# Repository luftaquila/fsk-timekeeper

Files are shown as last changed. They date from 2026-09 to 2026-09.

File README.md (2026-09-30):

# Formula Student Korea Timekeeper

Wireless LoRa timing instrument for Formula Student Korea dynamic events.

* One USB master, up to five battery-powered sensors (two in practice), one 921.3 MHz channel (KR920)
* Two modes: start → finish, laps (optional auto-stop)
* Console: one HTML file, Chrome / Edge (Web Serial)
  * https://luftaquila.github.io/fsk-timekeeper/
  * `fsk-timekeeper-console.html` from the [latest release](https://github.com/luftaquila/fsk-timekeeper/releases/latest)

## Usage notes

* The master is the board plugged into the console PC, and it must stay plugged in. Unplugged, it stops all radio activity; plugged back in, it starts a new session and any open run ends.
* Update the console and the firmware of every board together. The console refuses a master that reports another protocol version and says why.
* Flashing with several boards plugged in: `./flash.sh --serial <chip id>` (Windows: `.\flash.ps1 -Serial <chip id>`, not yet tested on Windows). The chip id is the 16-hex device id the console shows for the board; a board in the bootloader reports it too. A board still running a release from before chip-id serials reports 0001: give its port for that first update.

> [!NOTE]
> Assembly, usage and troubleshooting guides will follow.

## Development

<details>
<summary>click to expand</summary>

* Firmware
  * Requires: `arm-none-eabi-gcc` (with newlib-nano), `make`, `python3`
  * Build: `make -C device/firmware`
  * Test: `make -C device/firmware test`
* Console
  * Requires: Node.js 22
  * Build: `cd console && npm ci && npm run build:single`
  * Dev: `npm run dev` · Test: `npm test`
* Housings
  * Requires: OpenSCAD
  * Build: `make -C device/3d`
* Hardware
  * Requires: KiCad 10
  * Open: `device/hardware/fsk-timekeeper.kicad_pro`

</details>

## LICENSE

For non-commercial use only:

```
"THE BEERWARE LICENSE" (Revision 42):
LUFT-AQUILA wrote this project. As long as you retain this notice,
you can do whatever you want with this stuff. If we meet someday,
and you think this stuff is worth it, you can buy me a beer in return.
```

이 저장소의 모든 내용물은 비상업적 용도에 한해 얼마든지 자유롭게 사용할 수 있습니다.\
이 프로젝트가 마음에 든다면, 언젠가 우리가 만나게 되었을 때 맥주 한 잔 사 주세요.

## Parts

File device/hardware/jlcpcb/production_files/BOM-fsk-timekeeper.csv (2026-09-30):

Comment | Designator | Footprint | LCSC | Quantity
100nF | C1,C7 | C_0603_1608Metric | C14663 | 2
100pF | C5 | C_0603_1608Metric | C14858 | 1
10uF | C2,C3,C4,C8 | C_0603_1608Metric | C96446 | 4
110k | R2 | R_0603_1608Metric | C25805 | 1
1M | R1 | R_0603_1608Metric | C22935 | 1
330 | R3 | R_0603_1608Metric | C23138 | 1
4.7k | R4 | R_0603_1608Metric | C23162 | 1
47pF | C6 | C_0603_1608Metric | C1671 | 1
B5819W | D1 | D_SOD-123 | C8598 | 1
BAT54S | D2 | SOT-23 | C7420333 | 1
TPS61040DBV | U3 | SOT-23-5 | C7722 | 1

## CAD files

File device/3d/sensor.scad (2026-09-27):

// PCB Housing — FSK Timekeeper (wireless LoRa timing node) — SENSOR variant (sensor I/O only, no light)
// Board: 92 x 57 mm, corner r 3, 4x M2 mounting holes (86 x 51 rectangle),
// all tall components on the TOP side (18650 holder dominates the cavity height).
//
// Two parts:
//   lid  (본체 하우징)  — fully-rounded outer shell (ALL edges filleted) + ceiling + 4 self-tapping
//                         posts + connector cutouts + tripod boss. Open at the bottom.
//   base (바닥판)        — plate that inserts UP into the bottom opening of the lid (tucked under),
//                         carries the PCB on standoffs, fixed by the 4 screws into the lid posts.
//
// Assembly: M2 self-tapping screws inserted from OUTSIDE the base bottom pass through the
// base plate + PCB and self-tap into the posts hanging from the lid ceiling, pulling the
// base + PCB up against the posts and seating the base flush in the lid's bottom opening.
//
// Wall features (SENSOR variant — sensor I/O only; the light connector is not used):
//   - left  (-X): 1x Molex Mini-Fit Jr (J1 sensor +12V/SENSE). J2 (light GN/RD) opening is blanked off
//                 (solid wall). SMA antenna stays between the connector positions.
//   - right (+X): 1/4" tripod mount     (Ra-01 IPEX -> pigtail across the box -> antenna on the left)
//   - front (-Y): USB-C  (nRF52840 SuperMini) + 6mm toggle switch bushing (-Y wall, left)
//   - back  (+Y): blank
//
// Coordinate frame: PCB centred at XY origin; Z=0 at the outer bottom of the assembly.

/* [Rendering] */
part = "exploded";   // [base, lid, both, assembled, exploded]
show_pcb = true;     // PCB + 18650 reference in 'assembled' / 'exploded'
explode = 30;        // separation gap between stacked parts in 'exploded'

/* [PCB] */
pcb_l = 92;        // board length (X)
pcb_w = 57;        // board width  (Y)
pcb_r = 3;         // board corner radius
pcb_th = 1.6;      // board thickness
mount_inset = 3;   // mounting-hole inset from each edge (= corner radius)

/* [Shell] */
wall = 2.5;        // side wall thickness
lid_th = 2;        // lid ceiling thickness
base_th = 3;       // base plate thickness (>= edge_r so its bottom edge can be filleted)
pcb_clear = 0.5;   // gap between PCB edge and wall inner face
standoff_h = 2.5;  // PCB bottom height above base top (clears bottom-side 0603 caps ~0.5)
edge_r = 2.5;      // fillet radius for ALL outer edges of the body
batt_h = 21;       // *** ASSUMPTION: 18650 holder+cell height above PCB. MEASURE & adjust. ***
ra01_h = 6;        // *** ASSUMPTION: Ra-01 module height above PCB (limits how low the tripod box reaches). ***

/* [PCB-mount screws: base -> lid post, M2 self-tapping] */
post_d = 5.5;          // lid post outer diameter
post_style = "corner"; // [corner, rib, plain]
post_pad = 7;          // "corner" style: corner pad size
post_fillet = 2;       // "corner" style: rounding of the pad's cavity edge
post_rib = 2.4;        // "rib" style: rib thickness
post_pilot_d = 1.7;    // M2 self-tap pilot bore in post
post_pilot_depth = 16; // pilot depth up into post
so_d = 5.5;            // base standoff outer diameter
screw_clear_d = 2.6;   // M2 shaft clearance (through base + PCB)
head_d = 4.4;          // counterbore for screw head (base bottom)
head_h = 2;            // counterbore depth
base_fit = 0.3;        // base clearance per side inside the lid bottom opening

/* [Molex Mini-Fit Jr cutouts — left/-X wall] */
// KiCad +Y is screen-DOWN, OpenSCAD +Y is UP  ->  model_Y = 139.5 - boardY  (Y is flipped).
// Opening centre = connector WIDTH centre (pin centroid), NOT the footprint origin: the 2 circuits sit
// +2.1mm (local-X) from the origin -> J1 boardY 140.65 -> 139.5-(140.65-2.1) = 0.95; J2 -> -11.25.
molex_y = [0.95, -11.25];   // connector opening Y centres (model)
molex_cut_w = 11;          // opening width (Y) — clears the 9.6mm shroud (Molex SD-5569) + margin
molex_cut_h = 11;          // opening height above PCB (Z) — 9.6mm shroud + right-angle standoff (sensor variant: lowered 1mm, latch slot drops with it but keeps its height)
molex_latch_w = 4;         // latch slot width — clears the 3.0mm engaging tongue (Molex SD-5557 ".12[3.0]"); the 5.4mm is the external release handle, not through the wall (sensor variant: widened 0.5mm)
molex_latch_h = 4.5;       // latch slot extra height — must clear the latch at MAX deflection during mating (rest ~2.5mm + flex), not just at rest; SD shows rest only, so kept generous (sensor variant: net -0.5mm from baseline 5)

/* [USB-C cutout — -Y wall] */
// USB-C sits on the SuperMini's short end (board Y~167, at the -Y wall). Its X centre is the MODULE-WIDTH
// centre, NOT the footprint origin (origin = a corner pad): end pads span board X 140.47..155.71 ->
// centre 148.09 -> model 6.09. Port CENTRE height is measured 6.4mm above the PCB bottom face.
usb_x = 6.1;          // X centre of the USB-C port (model)
usb_cut_w = 13;       // opening width (X) incl. cable-boot clearance
usb_cut_h = 7;        // opening height (Z)
usb_above_bot = 6.4;  // port CENTRE height above the PCB bottom face (measured)

/* [Toggle switch bushing hole — -Y wall, LEFT (-X), clear of the Molex] */
// 6mm bushing toggle (MTS-/STM- 6mm series). The switch body needs a sw_cube clearance box
// reaching inward from the -Y wall; it is kept EAST (+X) of the Molex courtyard, which reaches
// model X -27.45 (J1 Y -4.35..+6.25, J2 Y -16.55..-5.95, Z 7.1..18), and ABOVE the PCB.
sw_d = 6;          // bushing through-hole (6mm toggle)
sw_cube = 14;      // required interior body-clearance cube (edge length)
sw_x = -15;        // hole X centre on the -Y wall (moved +5mm toward the tripod/+X side); cube -X edge -22 clears Molex (+X edge -27.45)
sw_z = 19;         // hole Z centre: cube spans z 12..26 -> above PCB + low parts (incl. L1 ~z10), below ceiling 37.6

/* [SMA antenna hole — -X (left) wall] */
// sensor variant (J2/light blanked off): bore centred above box mid-height (Z), and in Y midway between
// the -Y end of the J1 (sensor) opening and the -Y inner wall, nudged toward the connector, into the
// wall freed where J2 used to be.  (ant_y/ant_z are computed in the derived section, where inner_w exists.)
ant_d = 6.5;                             // SMA bulkhead through-hole

/* [Tripod mount — +X (right) wall, ceiling-integrated box (prints support-free)] */
// On the right wall (antenna side). A box hangs from the ceiling (fused to ceiling + wall; printed
// ceiling-down it is a solid column off the bed -> no support) and extends DOWN to the 1/4" bore,
// which sits at the vertical CENTRE of the face. At Y=0 the battery is absent (cell ends ~Y+8, the
// +X contact is at Y+14..+21), so only the low Ra-01 module limits how far down the box reaches.
tri_box_w = 12;    // box width (Y)
tri_y = -1.5;      // box Y centre — shifted -Y off the face centre so it clears the battery holder body (-Y edge ~ +6.75)
tri_box_d = 10;    // box depth into the cavity (X from the wall)
tri_pilot_d = 5.7; // 1/4"-20 self-tap pilot in plastic (was 5.4 — too tight to thread in)
tri_depth = 8;     // thread engagement depth from the outer wall face
tri_gap = 2;       // clearance between the box bottom and the Molex envelope

/* [Quality] */
$fn = 64;

// ---------- derived ----------
inner_l = pcb_l + 2*pcb_clear;
inner_w = pcb_w + 2*pcb_clear;
outer_l = inner_l + 2*wall;
outer_w = inner_w + 2*wall;
inner_r = pcb_r + pcb_clear;
outer_r = inner_r + wall;

base_l = inner_l - 2*base_fit;       // plugs the bottom opening
base_w = inner_w - 2*base_fit;
base_r = inner_r - base_fit;

pcb_bot_z = base_th + standoff_h;    // PCB underside
pcb_top_z = pcb_bot_z + pcb_th;      // PCB top surface
usb_z     = pcb_bot_z + usb_above_bot;   // USB-C port centre Z (measured from the PCB bottom face)
// height: max of battery, latch-slot reach, and "tripod bore at face centre while its box clears the Ra-01"
cavity    = max(batt_h + tri_gap, molex_cut_h + molex_latch_h + 2, 2*(pcb_top_z + ra01_h + 4 + tri_pilot_d/2) - pcb_top_z - lid_th);
ceil_z    = pcb_top_z + cavity;      // lid inner ceiling
outer_h   = ceil_z + lid_th;         // overall height
post_len  = ceil_z - pcb_top_z;      // = cavity

tri_hole_z  = outer_h/2;                          // 1/4" bore at the vertical CENTRE of the right face
tri_box_bot = pcb_top_z + ra01_h + 2;             // box hangs from the ceiling down to here (clears the Ra-01 module)
ant_y       = ((molex_y[0] - molex_cut_w/2) + (-inner_w/2)) / 2 + 1;   // midway: sensor-hole -Y end <-> -Y inner wall, +1mm toward the connector
ant_z       = outer_h/2 + 8;                      // sensor variant: above box mid-height

mx = pcb_l/2 - mount_inset;          // 43
my = pcb_w/2 - mount_inset;          // 25.5
mount_pos = [[-mx,-my],[mx,-my],[-mx,my],[mx,my]];

eps = 0.01;
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

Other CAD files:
device/3d/master.scad

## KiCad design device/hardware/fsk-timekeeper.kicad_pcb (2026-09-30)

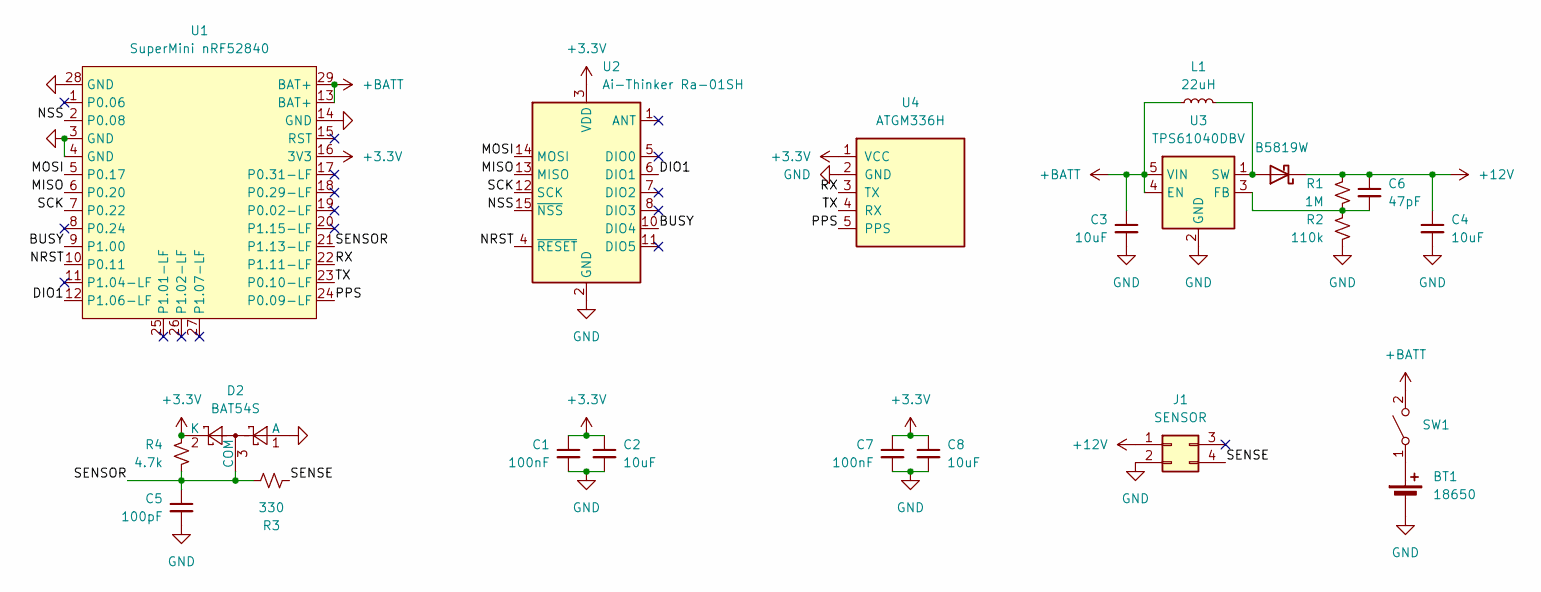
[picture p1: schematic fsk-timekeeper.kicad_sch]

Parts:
BT1: 18650; BatteryHolder_Keystone_1042_1x18650
C1, C7: 100nF; C_0603_1608Metric; LCSC C14663
C2, C3, C4, C8: 10uF; C_0603_1608Metric; LCSC C96446
C5: 100pF; C_0603_1608Metric; LCSC C14858
C6: 47pF; C_0603_1608Metric; LCSC C1671
D1: B5819W; D_SOD-123; LCSC C8598
D2: BAT54S; SOT-23; LCSC C7420333
J1: SENSOR; Molex_Mini-Fit_Jr_5569-04A2_2x02_P4.20mm_Horizontal
L1: 22uH; L_Sunlord_MWSA0603S
R1: 1M; R_0603_1608Metric; LCSC C22935
R2: 110k; R_0603_1608Metric; LCSC C25805
R3: 330; R_0603_1608Metric; LCSC C23138
R4: 4.7k; R_0603_1608Metric; LCSC C23162
SW1: SW_SPST; PinHeader_1x02_P2.54mm_Vertical
U1: SuperMini nRF52840; SuperMini_NRF52840
U2: Ai-Thinker Ra-01SH; Ai-Thinker-Ra-01-LoRa
U3: TPS61040DBV; SOT-23-5; LCSC C7722
U4: ATGM336H; ATGM336H_GPS_Module

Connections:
+3.3V: C1.1, C2.1, C7.1, C8.1, D2.2 (K), R4.2, U1.16 (3V3), U2.3 (VDD), U4.1 (VCC)
+12V: C4.1, C6.1, D1.1 (K), J1.1, R1.1
+BATT: C3.1, L1.1, SW1.2 (B), U1.13 (BAT+), U1.29 (BAT+), U3.4 (EN), U3.5 (VIN)
/BUSY: U1.9 (P1.00), U2.10 (DIO4)
/DIO1: U1.12 (P1.06-LF), U2.6 (DIO1)
/MISO: U1.6 (P0.20), U2.13 (MISO)
/MOSI: U1.5 (P0.17), U2.14 (MOSI)
/NRST: U1.10 (P0.11), U2.4 (~RESET)
/NSS: U1.2 (P0.08), U2.15 (~NSS)
/PPS: U1.24 (P0.09-LF), U4.5 (PPS)
/RX: U1.22 (P1.11-LF), U4.3 (TX)
/SCK: U1.7 (P0.22), U2.12 (SCK)
/SENSE: J1.4, R3.1
/SENSOR: C5.1, D2.3 (COM), R3.2, R4.1, U1.21 (P1.13-LF)
/TX: U1.23 (P0.10-LF), U4.4 (RX)
GND: BT1.2 (-), C1.2, C2.2, C3.2, C4.2, C5.2, C7.2, C8.2, D2.1 (A), J1.2, R2.2, U1.3 (GND), U1.4 (GND), U1.14 (GND), U1.28 (GND), U2.2 (GND), U2.9 (GND), U2.16 (GND), U3.2 (GND), U4.2 (GND)
unnamed: BT1.1 (+), SW1.1 (A)
unnamed: D1.2 (A), L1.2, U3.1 (SW)
unnamed: C6.2, R1.2, R2.1, U3.3 (FB)

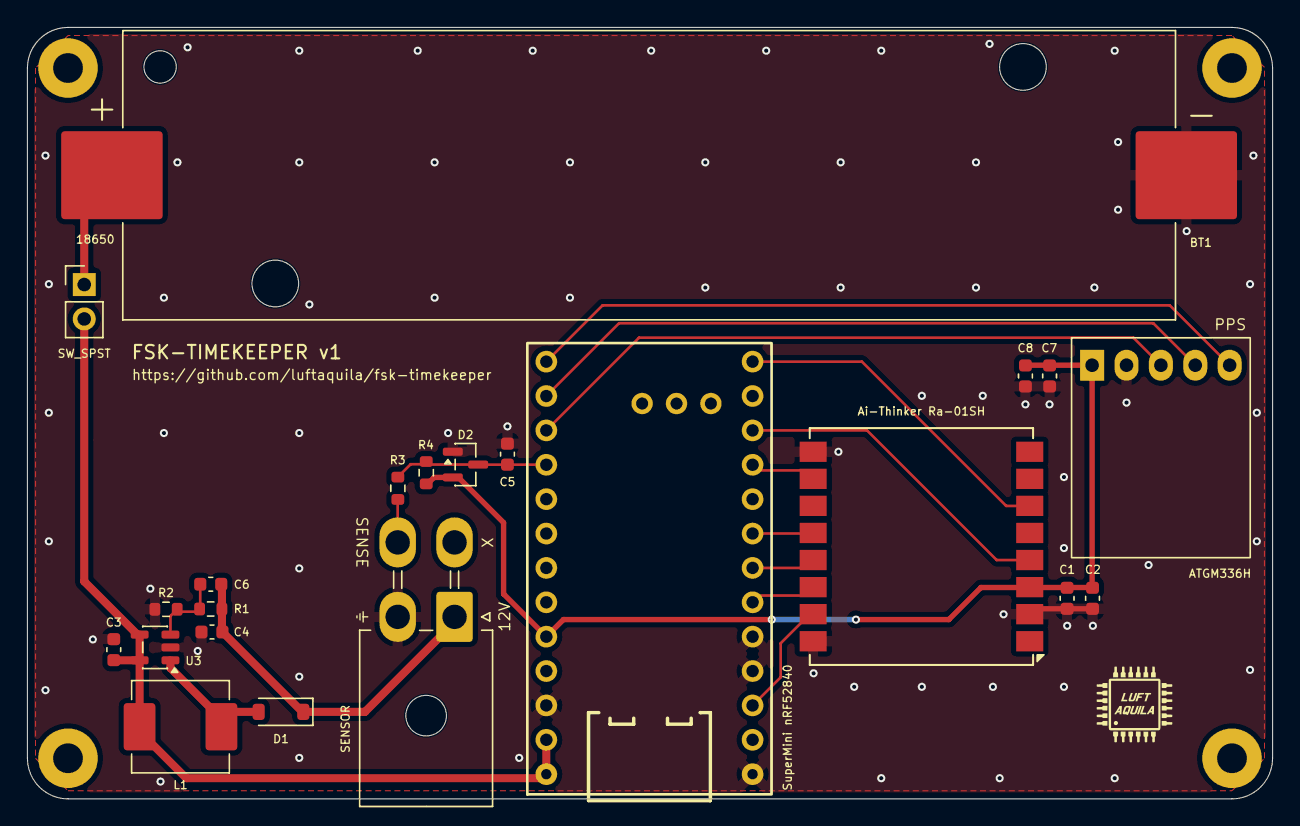
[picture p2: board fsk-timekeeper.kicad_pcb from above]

Board: 2 copper layers, 92.0 x 57.0 mm, 22 parts (0 on the bottom side), 19 nets.

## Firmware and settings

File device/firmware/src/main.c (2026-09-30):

/* One master and up to MAX_NODES sensors on one channel and one timebase; one
 * binary, role decided at boot from USB (DESIGN §8).
 *
 * MASTER = the board a PC enumerates over USB-CDC: beacons, collects sensor
 * records into the host queue and speaks the FSK-WL line protocol (proto_usb.h).
 * SENSOR = any other board: syncs to beacons, captures SENSOR edges in hardware
 * and uplinks them in its slot (mac_sensor.h).
 */
#include <stdint.h>
#include <stddef.h>

#include "board.h"
#include "capture.h"
#include "config.h"
#include "errlog.h"
#include "fault.h"
#include "gpio.h"
#include "gps.h"
#include "keystore.h"
#include "mac_master.h"
#include "mac_sensor.h"
#include "master_queue.h"
#include "meas.h"
#include "node_id.h"
#include "power.h"
#include "proto_usb.h"
#include "radio.h"
#include "secure.h"
#include "usb.h"
#include "nrf.h"

/* Pump USB up to ROLE_SETTLE_MS for a PC to enumerate us: master when one does.
 * Decided once; a host that later suspends the bus does not change it. */
static int role_decide_master(void)
{
    uint32_t t0 = board_millis();
    for (;;) {
        usb_task();
        if (usb_host_present()) { return 1; }
        if ((uint32_t)(board_millis() - t0) >= ROLE_SETTLE_MS) { return 0; }
    }
}

/* `K <64-hex>` on any board: write the fleet key and use it at once. There is no
 * read-back command. */
static void provision_key(void)
{
    if (keystore_write(pu_setkey()) == 0) {
        sec_reload();
        pu_emit_ack("K");
    } else {
        pu_emit_err("keyfail");
    }
}

static void service(uint32_t now)
{
    usb_task();
    pu_service(now);
    fault_service(now);
    board_hfxo_service();
}

/* ===== bring-up ========================================================== */

/* Radio, TIMER1 and the role's captures; 0 when up. Fail closed: no radio or
 * TIMER1 work on HFINT. Until it is up the board keeps USB provisioning and
 * retries with backoff. */
static int bring_up(int master)
{
    if (!board_hfclk_xtal()) { return -1; }
    int st = radio_begin();
    if (st != 0) { return st; }
    capture_init();
    if (master) {
        capture_pps_enable();
        gps_init();
    } else {
        capture_sensor_enable();
    }
    return 0;
}

typedef struct {
    uint32_t at_ms;
    uint32_t backoff_ms;
} retry_t;

static void retry_init(retry_t *r)
{
    r->backoff_ms = RADIO_BOOT_RETRY_MS;
    r->at_ms = board_millis() + r->backoff_ms;
}

/* 1 once a due retry has brought the board up. */
static int retry_bring_up(retry_t *r, int master, uint32_t now)
{
    if ((int32_t)(now - r->at_ms) < 0) { return 0; }
    el_note(EL_RADIO_RESET);
    if (bring_up(master) == 0) { return 1; }
    r->backoff_ms = r->backoff_ms * 2u > RADIO_RESET_BACKOFF_MAX_MS ? RADIO_RESET_BACKOFF_MAX_MS : r->backoff_ms * 2u;
    r->at_ms = board_millis() + r->backoff_ms;
    return 0;
}

/* ===== sensor ============================================================ */

static mac_sensor_t g_sensor;

static void run_sensor(int st)
{
    if (st == 0) { mac_sensor_init(&g_sensor, node_sender_id(), fault_reset_reason()); }
    retry_t retry;
    retry_init(&retry);
    uint32_t last_blink = board_millis();
    for (;;) {
        uint32_t now = board_millis();
        service(now);
        int c;
        while ((c = usb_read_byte()) >= 0) {
            switch (pu_feed(c)) {
            case PU_CMD_SETKEY: provision_key(); break;
            case PU_CMD_ID:
                pu_emit_identity(node_devid_hi(), node_devid_lo(), 0, fault_reset_reason());
                pu_emit_ack("ID");
                break;
            case PU_CMD_PING: pu_emit_ack("PING"); break;
            case PU_CMD_BAD: pu_emit_err("badcmd"); break;
            default: break;
            }
        }
        if (st != 0) { /* no radio / no crystal: provisioning, and a retry now and then */
            if (retry_bring_up(&retry, 0, now)) {
                st = 0;
                mac_sensor_init(&g_sensor, node_sender_id(), fault_reset_reason());
                continue;
            }
            if ((uint32_t)(now - last_blink) >= 1000u) { last_blink = now; board_led_toggle(); }
            continue;
        }
        mac_sensor_step(&g_sensor);
    }
}

/* ===== master ============================================================ */

static mq_t g_queue;
static mac_master_t g_mac;
static uint32_t g_hfxo_stops; /* board_hfxo_stops() already handled */

/* A master HFXO fault ends the timebase session: its marker is queued ahead of
 * any record of the new session, which starts once the crystal is back. A stop
 * whose restart already finished counts too. */
static int master_clock_check(void)
{
    static int faulted, reported;
    static uint64_t at;
    static uint32_t boot;
    uint32_t stops = board_hfxo_stops();
    int stopped = stops != g_hfxo_stops;
    g_hfxo_stops = stops;
    if ((!board_hfclk_xtal() || stopped) && !faulted) {
        at = capture_now64();
        boot = sec_boot_id();
        faulted = 1;
        reported = 0;
    }
    if (!faulted) { return 1; }
    /* A full host queue holds the marker back until there is room: a retry on
     * every pass is no overflow. */
    if (!reported && !mq_full(&g_queue)) { reported = mq_push_timebase_end(&g_queue, boot, at); }
    if (reported && board_hfclk_xtal()) {
        sec_init();
        mac_master_session(&g_mac);
        faulted = 0;
        return 1;
    }
    return 0;
}

/* Node 0 self-report: die temperature, charge rail, security and queue counters. */
static void emit_self(int timebase_ok)
{
    pu_diag_t d = {0};
    d.is_master = 1;
    d.state = timebase_ok ? PU_STATE_OK : PU_STATE_LOST;
    d.temp_c10 = meas_temp_c10();
    d.batt_mv = meas_vddh_mv();
    d.sec_drop = g_mac.auth_drop;
    d.provisioned = sec_provisioned();
    d.health = (uint8_t)((timebase_ok ? (HEALTH_SYNC_VALID | HEALTH_SKEW_VALID) : 0u) |
                         (board_hfclk_xtal() ? HEALTH_CLOCK_XTAL : 0u));
    d.sync_age_ms = timebase_ok ? 0 : UINT16_MAX;
    d.queue_depth = (uint16_t)mq_depth(&g_queue);
    d.queue_overflow = g_queue.overflow;
    d.err_flags = el_flags();
    d.ver_drop = g_mac.ver_drop;
    d.tx_drop = pu_tx_drop();
    d.reset_reason = fault_reset_reason();
    d.master_boot_id = sec_boot_id();
    pu_emit_diag(&d);
}

static void emit_pps(void)
{
    gps_report_t g;
    gps_report(&g);
    pu_emit_pps(g.pps_tick, g.utc_s, g.ppb, g.pps_valid, g.fix, g.sats, g.span_s, g.seg, g.n);
}

/* USB unplugged: stop every radio activity until VBUS returns, then reboot
 * into a new session. A battery-less master simply loses power. */
static void master_stopped(mp_state_t *power, int radio_up)
{
    if (radio_up) { radio_standby(); }
    board_led_off();
    uint32_t t0 = board_millis();
    for (;;) {
        usb_task();
        if (mp_step(power, usb_vbus_present()) == MP_RESET) { NVIC_SystemReset(); }
        gpio_write(PIN_LED_STATUS, (board_millis() - t0) % 2000u < 100u); /* short flash every 2 s */
    }
}

/* Identity and the fault that rebooted us, before the radio comes up: a bring-up
 * that hangs must not keep the cause from the host. */
static void master_hello(void)
{
    pu_emit_identity(node_devid_hi(), node_devid_lo(), 1, fault_reset_reason());
    uint32_t pc, lr, cfsr;
    const char *cause;
    if (fault_take_report(&pc, &lr, &cause, &cfsr)) { pu_emit_fault(pc, lr, cause, cfsr); }
}

static void run_master(int st)
{
    mq_init(&g_queue);
    g_hfxo_stops = board_hfxo_stops();
    if (st == 0) { mac_master_init(&g_mac, &g_queue); }

    mp_state_t power = MP_RUN;
    retry_t retry;
    retry_init(&retry);
    uint32_t last = board_millis();
    uint8_t idle_seq = 0;
    for (;;) {
        uint32_t now = board_millis();
        service(now);
        if (mp_step(&power, usb_vbus_present()) == MP_STOP) { master_stopped(&power, st == 0); }
        el_report(now);

        int c;
        while ((c = usb_read_byte()) >= 0) {
            switch (pu_feed(c)) {
            case PU_CMD_ID:
                pu_emit_identity(node_devid_hi(), node_devid_lo(), 1, fault_reset_reason());
                pu_emit_ack("ID");
                break;
            case PU_CMD_STATUS:
                pu_emit_heartbeat(st == 0 ? capture_now64() : 0, now,
                                  st == 0 ? (uint8_t)(g_mac.seq - 1u) : idle_seq,
                                  st == 0 ? (int)reg_count(&g_mac.reg) : 0);
                if (st == 0) { mac_master_report(&g_mac, 0); }
                emit_self(st == 0);
                if (st == 0) { emit_pps(); }
                pu_emit_ack("STATUS");
                break;
            case PU_CMD_PING:
                pu_emit_ack("PING");
                break;
            case PU_CMD_SETKEY:
                provision_key();
                break;
            case PU_CMD_EVENT_ACK:
                (void)mq_ack(&g_queue, pu_ack_hseq(), pu_ack_boot(), pu_ack_crc());
                break;
            case PU_CMD_CLOCK:
                if (st != 0) { pu_emit_err("clock"); break; }
                pu_emit_clock(pu_clock_token(), capture_now64(), sec_boot_id());
                break;
            case PU_CMD_CHECKPOINT:
                if (st != 0) { pu_emit_err("clock"); break; } /* no beacons without a timebase */
                mac_master_checkpoint(&g_mac);
                pu_emit_ack("CP");
                break;
            case PU_CMD_BAD:
                pu_emit_err("badcmd");
                break;
            default:
                break;
            }
        }
        mq_pump(&g_queue, now);

        if (st != 0) {
            if (retry_bring_up(&retry, 1, now)) {
                st = 0;
                g_hfxo_stops = board_hfxo_stops();
                mac_master_init(&g_mac, &g_queue);
                continue;
            }
            if ((uint32_t)(now - last) >= 1000u) {
                last = now;
                pu_emit_heartbeat(0, now, idle_seq++, 0);
                if ((uint8_t)(idle_seq % CHECKPOINT_PERIOD_BEACONS) == 0u) { emit_self(0); }
            }
            continue;
        }
        if (!master_clock_check()) { continue; }
        gps_poll();
        if (gps_report_due()) { emit_pps(); }

        if (mac_master_step(&g_mac)) {
            uint8_t sent = (uint8_t)(g_mac.seq - 1u);
            /* Without a key sec_seal refuses: no beacon goes out; tell the PC. */
            if (!sec_provisioned() && (sent % 5u) == 0u) { pu_emit_err("noprov"); }
            pu_emit_heartbeat(capture_now64(), now, sent, (int)reg_count(&g_mac.reg));
            mac_master_report(&g_mac, 1);
            if ((uint8_t)(g_mac.seq % CHECKPOINT_PERIOD_BEACONS) == 0u) { emit_self(1); }
        }
    }
}

int main(void)
{
    fault_boot(); /* may halt after repeated fault reboots */
    board_init();
    node_init();
    sec_init();   /* boot_id + key before any sealed TX */
    usb_init();

    int master = role_decide_master();
    if (master) { master_hello(); }

    /* USB may have started HFXO while the role was being resolved: check the
     * clock source only now. */
    int st = bring_up(master);

    if (master) {
        run_master(st);
    } else {
        run_sensor(st);
    }
}

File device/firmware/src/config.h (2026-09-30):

/* Board pin map (DESIGN §4) and firmware parameters.
 *
 * SuperMini nRF52840 numbering: P0.n == n, P1.n == 32 + n. Capture pins on
 * port 1 need the PORT bit in GPIOTE PSEL (capture.c).
 */
#ifndef CONFIG_H
#define CONFIG_H

#define PIN(port, n) ((port) * 32 + (n))

/* Onboard status LED. Polarity unverified (DESIGN §10); blinking works either way. */
#define PIN_LED_STATUS PIN(0, 15)

/* LoRa radio (Ra-01SH / SX1262) — SPIM + control */
#define PIN_LORA_SCK   PIN(0, 22)
#define PIN_LORA_MISO  PIN(0, 20)
#define PIN_LORA_MOSI  PIN(0, 17)
#define PIN_LORA_NSS   PIN(0, 8)
#define PIN_LORA_BUSY  PIN(1, 0)
#define PIN_LORA_DIO1  PIN(1, 6)  /* GPIOTE capture (Tx/RxDone) — port 1 */
#define PIN_LORA_NRST  PIN(0, 11) /* radio reset (NOT the board RST pin) */

/* Sensor input (BA2M NPN open-collector, falling edge) — sensor role */
#define PIN_SENSOR_IN  PIN(1, 13) /* GPIOTE capture (falling) — port 1 */

/* GPS (ATGM336H breakout, master only; sensor boards leave U4 unpopulated).
 * P0.09/P0.10 are the NFC antenna pins until board_init() clears UICR.NFCPINS. */
#define PIN_GPS_PPS    PIN(0, 9)  /* 1PPS in — GPIOTE capture (rising) */
#define PIN_GPS_RXD    PIN(1, 11) /* UARTE0 RXD <- GPS TXD (NMEA, 9600 8N1) */
#define PIN_GPS_TXD    PIN(0, 10) /* UARTE0 TXD -> GPS RXD (CASIC config commands) */

/* VCC enable gate — driven HIGH at boot (DESIGN §8) */
#define PIN_EXT_POWER  PIN(0, 13)

/* LoRa radio parameters (DESIGN §2.1/§2.2, KR920): one channel shared by the
 * master and every sensor. */
#define LORA_FREQ_MHZ   921.3f
#define LORA_BW_KHZ     250.0f  /* SF7/BW250, symbol 512 us */
#define LORA_SF         7
#define LORA_CR         5       /* coding rate 4/5 */
#define LORA_SYNCWORD   0x12
#define LORA_POWER_DBM  12      /* conducted ~+12 dBm -> EIRP <= +14 dBm with ~2 dBi */
#define LORA_PREAMBLE   8
#define LORA_TCXO_V     1.6f    /* Ra-01SH TCXO via DIO3 */

#define TICKS_PER_MS 16000u /* TIMER1 runs at 16 MHz */

/* Fixed TxDone->RxDone air delay in ticks (DESIGN §2.9). Cancels in
 * sensor-to-sensor intervals; 0 until measured. */
#define T_AIR_REF_TICKS 0u

/* Frame timing (DESIGN §2.8): a beacon every BEACON_PERIOD_MS on a TIMER1 grid; slot k starts
 * SLOT_OFFSET_MS + k * SLOT_LEN_MS after its RxDone and holds a ~77 ms uplink. A TX let through
 * at SLOT_LATE_MS is on air <= ~7 ms later (SPI + TCXO start after a CAD) and ends by ~99 ms. */
#define BEACON_PERIOD_MS   1000u
#define SLOT_OFFSET_MS     50u
#define SLOT_LEN_MS        100u
#define SLOT_LATE_MS       15u  /* latest TX start within a slot; later -> skip this cycle */
#define BEACON_LBT_MAX_MS  50u  /* re-sense a busy channel this long, then send the beacon anyway */
#define RX_DRAIN_MAX_MS    100u /* longest wait for a reception in progress before a CAD */
#define RX_HEADER_WAIT_MS  12u  /* a preamble without a header after this long is noise */
#define CAD_TIMEOUT_MS     10u  /* a CAD takes ~2.5 ms (4 symbols at SF7/BW250), ~7.5 ms after a TCXO start */

/* Periodic checkpoint + diagnostics: in the beacon whose seq % this == slot % this. */
#define CHECKPOINT_PERIOD_BEACONS 5u
/* A checkpoint request (host `CP`) rides this many consecutive beacons. */
#define CP_REQ_BEACONS 2u

/* Sensor link state at the master from the time since its last uplink
 * (reported on D lines; the console uses only this state). */
#define LINK_OK_MS    12000u
#define LINK_STALE_MS 17000u

/* A capture may be stamped normally while its offset anchor is this fresh. At the
 * worst-case 80 ppm relative drift this contributes <= 0.56 ms. */
#define SYNC_TTL_MS 7000u
/* Captures taken while the anchor is staler are held in local ticks and
 * interpolated between the anchors around them when those are at most this far
 * apart; otherwise they become losses of unknown time. */
#define SYNC_HOLD_MAX_MS 60000u

/* Skew correction (DESIGN §2.5): only for a plausible estimate from enough samples over a long
 * enough span, at most SKEW_MAX_EXTRAP_MS past the anchor. The raw estimate is still reported
 * so an RC fallback (~10000 ppm) stays visible. */
#define SKEW_CLAMP_PPM      100      /* max plausible XO drift; a real XO is < +-40 ppm */
#define SKEW_MIN_SAMPLES    4u       /* offset samples required before trusting the slope */
#define SKEW_MIN_DL_TICKS   8000000u /* min local-tick span of a skew sample (~0.5 s) */
#define SKEW_MAX_EXTRAP_MS  SYNC_TTL_MS

/* Evidence buffers. The sensor keeps every record until the master has taken it
 * (cumulative ACK in the beacon); when the FIFO is full, new captures accumulate
 * into one loss range. The master keeps a record until the host acks its line. */
#define SENSOR_FIFO_LEN        256u
#define MASTER_EVENT_QUEUE_LEN 16u
#define MASTER_USB_RETRY_MS    100u
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

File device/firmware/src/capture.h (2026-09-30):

/* Hardware timestamp capture on TIMER1 (DESIGN §2.4, §8).
 *
 * TIMER1 free-runs at 16 MHz (62.5 ns) and is extended to 64 bits in software.
 * GPIOTE -> PPI latches DIO1 (Tx/RxDone), SENSOR and GPS PPS edges into TIMER1
 * CC registers with no CPU latency; a 32-bit capture is widened against the
 * current time. capture_now64() must run at least once per ~268 s wrap.
 * Main-loop context except where noted.
 */
#ifndef CAPTURE_H
#define CAPTURE_H

#include <stdint.h>

/* TIMER1 + DIO1 capture (both roles). */
void capture_init(void);
/* SENSOR input capture into a 64-entry ISR ring (sensor role). */
void capture_sensor_enable(void);
/* GPS PPS capture on its own GPIOTE/PPI channel (master role). */
void capture_pps_enable(void);

uint64_t capture_now64(void);

/* Latest DIO1 rising edge since the last call (1), or none (0). */
int capture_dio1_get(uint64_t *tick);

/* Oldest SENSOR edge from the ring: capture seq (counts every edge, lost ones
 * included) and whether HFXO ran when it was taken. */
int capture_sensor_get(uint64_t *tick, uint32_t *seq, int *clock_xtal);
/* Edges the full ring had to drop, as a seq/tick range; it follows every edge
 * still in the ring. Drain with capture_sensor_get() first, then this, until
 * both return 0. */
int capture_sensor_loss(uint64_t *first_tick, uint64_t *last_tick, uint32_t *first_seq, uint32_t *last_seq);
/* Now and the seq of the last edge; returns 1 only when no edge is pending
 * anywhere (ring, loss, latched event), i.e. the pair may be a checkpoint. */
int capture_sensor_checkpoint(uint64_t *tick, uint32_t *seq);
/* Ring overflows since boot (diagnostic). */
uint16_t capture_sensor_overflow(void);

/* Latest PPS rising edge since the last call (1), or none (0). */
int capture_pps_get(uint64_t *tick);

#endif /* CAPTURE_H */

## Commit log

2026-09-27 add: import wireless timing device from formula-student-korea@b5917225
    Hardware (KiCad 10, renamed fsk-traffic -> fsk-timekeeper, project-local libraries), nRF52840 firmware (plain Makefile that clones the pinned deps; protocol and USB identity unchanged; the I line rep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
    [fsk-timekeeper.kicad_pcb, fsk-timekeeper.kicad_sch, master.scad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]
2026-09-27 ci: firmware, kicad, 3d, console html, pages and release workflows
    Release on v* tags assembles fsk-timekeeper-{firmware,pcb,3d}.zip and fsk-timekeeper-console.html; the firmware build reports the tag as its version. The firmware zip ships flash.sh / flash.ps1 / fla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
2026-09-27 add: console (Vite + Vue, single-file build)
    Web Serial bridge to the FSK-WL master: timing engine with two mechanism modes (start -> finish, laps with optional auto-stop), one run at a time, quality gate, IndexedDB event log with host acks, re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
2026-09-28 add: GPS on the master — ATGM336H, PPS clock calibration, new pin map
    Hardware: ATGM336H breakout (U4, master boards only) with a project-local symbol
    and footprint; SENSOR moves to P1.13, GPS PPS/RXD/TXD take P0.09/P1.11/P0.10.
    Firmware: pin map in config.h; board.c clears UICR.NFCPINS.PROTECT once per
    board (readback-guarded reset); the idle SENSOR capture channel captures PPS
    on the master; gps.c drives UARTE0 (NMEA, GGA+RMC via $PCAS03), parses fix,
    satellites and UTC, and estimates the HFXO error from an 8-64 s window of
    gated PPS edges. Reported on the new `P` line (~1 Hz, also in ?STATUS); wire
    ticks stay raw, the console applies the correction.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
    [fsk-timekeeper.kicad_pcb, fsk-timekeeper.kicad_sch]
2026-09-28 add: apply the master GPS calibration to results
    Parse the `P` line, freeze the valid PPS estimate into the run at START
    (run.calib) and convert ticks with the exact rational
    ms = (ticks*125000 + D) / (2D), D = 1e9 + ppb; nominal 16 MHz without GPS.
    Runs get a UTC start time from the PPS<->RMC association; history and CSV
    record hfxo_ppb and started_utc. Diagnostics shows the GPS drift and fix,
    the result badge says GPS-calibrated or nominal, the simulator has GPS
    toggles. history.upsert copies the raw row so nested objects survive the
    IndexedDB structured clone.
2026-09-28 add: checkpoint on demand over the beacon (PROTO_VER 10)
    The beacon carries cp_req, a request id; every synced sensor answers each id
    once with an immediate checkpoint as soon as its own events are acked. The
    master raises a new id when it queues a fresh sensor capture/loss event and on
    the new host command `CP`, and repeats it on CP_REQ_BEACONS (2) consecutive
    beacons. Sprint completion and a stopped run's confirmation now take ~1 s
    instead of the 5 s periodic checkpoint, and the extra traffic exists only when
    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
2026-09-28 fix: count crossings on arrival, keep evidence after Stop, freeze the debounce
    - A healthy capture whose seq follows the previous one confirms its sensor's
    stream through its own tick (nothing can sit between consecutive seqs), so a
    single-sensor lap counts the moment its crossing arrives; a pending loss still
    waits for the checkpoint. Other sensors' silence is confirmed as before.
    - Stop no longer closes the run: it records the master's stop tick, keeps
    counting crossings captured before it, ignores later ones, and closes once
    every sensor is confirmed through the stop tick. Meanwhile the console asks
    the master for checkpoints (`CP`, retried every 2 s). A master reboot before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
2026-09-28 fix: Stop needs a real fence; faults after it leave the record alone
    - Stop takes its fence from the master (`T`), or from the latest heartbeat
    (<= 10 s, same boot) when `T` fails; without either it is refused and the
    run stays armed. The old fallback to the latest evidence tick fenced in the
    past and silently dropped crossings still in flight.
    - A fault whose tick is certainly after the fence no longer invalidates the
    stopped run; unknown-time losses and session ends (master timebase change,
    sensor reboot) still do.
    - The simulator's own checkpoint requests can be switched off; tests keep
    checkpoints under manual control except one that exercises the request.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
2026-09-28 fix: accept PPS edges for the HFXO estimate only under a valid fix
    A receiver without a fix (or in holdover) can keep pulsing from its own TCXO;
    that pulse is stable enough to pass the deviation gate but is no UTC
    reference. Edges now enter the estimation window only while RMC reports a
    valid fix, the window restarts on every fix transition, and the report is
    invalid without one. Unfixed edges still anchor the UTC association.
    [gps.c]
2026-09-28 fix: expire GPS reference qualification and rebuild calibration windows
    [config.h, gps.c]
2026-09-30 fix: rebuild device firmware on radio protocol v11 and USB protocol v2
    Radio v11: the master beacons every second on a TIMER1 grid and gives each
    sensor a slot. The beacon's slot table carries a cumulative ACK, so a sensor
    keeps every record (a 256-entry FIFO without expiry; overflow becomes one
    loss range) until the master has taken it. Captures taken while beacons are
    missing are held and interpolated between the anchors around them. One
    uplink type carries edges, a loss range or a checkpoint, plus diagnostics.
    USB v2: event lines carry a host sequence number and a CRC-32 and stay
    queued until the console acks them; control lines are retried, periodic
    lines may drop and are counted. The I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
    [board.c, capture.c, capture.h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]
2026-09-30 fix: rebuild console timing on the v2 device protocol
    Crossings are judged on per-sensor timelines and combined per role, with
    pending, verified, invalid and DNF states and the fault window that caused
    them. Result ticks are converted to GPS seconds on the PPS timeline with
    exact rationals and frozen per run once the result is decided.
    Storage moves to IndexedDB v2 with strict durability: an event line is acked
    only after it is stored, malformed lines are quarantined, and a master of
    another protocol version is refused with the reason. X lines and reset
    reasons are kept in a device log.
2026-09-30 add: flash a board chosen by its chip id
    flash.sh --serial and flash.ps1 -Serial pick the app board whose USB serial
    number is the given chip id; the Windows script is not yet tested. The
    README and the release notes also say that the console and every board must
    be updated together and that the master must stay plugged in.
2026-09-30 add: reboot through the fault path when a radio call hangs
    Two RadioLib waits poll BUSY with no timeout: the calibration wait in
    begin() and the PA ramp wait after SetTx. NrfHal now overrides yield(),
    which every RadioLib BUSY loop calls. BUSY staying high for RADIO_HANG_MS
    within one radio call, with no SPI transfer in between, is a hung radio: the
    board records a fault with cause "radio" and the waiting code's address, and
    reboots. Bounded waits end within RADIO_SPI_TIMEOUT_MS, so normal operation
    never comes near the limit. A radio still hung after the reboot fails the
    probe and the board comes up without it.
    [config.h, fault.c, radio.cpp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]
2026-09-30 fix: keep the radio TCXO running in standby
    The radio's standby ran on its RC oscillator, so every RX, TX and CAD first
    waited 5 ms for the TCXO. After begin() the radio now switches to the TCXO
    standby and falls back to it after RX and TX: a CAD takes ~2.5 ms instead of
    ~7.5 ms and reception restarts without the wait. begin() itself still runs
    on the RC standby, since the TCXO only answers to DIO3 once begin() has
    reset and configured the chip, and a failed switch counts as a failed
    begin(). The slot budget keeps a TCXO start before the TX, as a CAD may end
    on the RC oscillator.
    [config.h, radio.cpp]
2026-09-30 fix: park the radio with its TCXO off while the master is stopped
    radio_standby() only parks the radio of a master whose USB is unplugged.
    With the standby now on the TCXO, a battery-powered master would have kept
    the TCXO running for the whole stop; it now parks in the RC standby.
    [radio.cpp]
2026-09-30 fix: leave the Ra-01SH TXEN and RXEN pins unconnected
    The Ra-01SH ties TXEN to the SX1262 DIO2 through a 0 ohm resistor and
    leaves RXEN open, and RadioLib's begin() already makes DIO2 drive the RF
    switch. Driving TXEN from P1.04 fought DIO2 at the start and end of every
    transmission, and RXEN reached nothing. The schematic and board drop both
    nets, and the firmware drops setRfSwitchPins() and the pin definitions.
    The board also carries the refilled GND zone, the bottom +BATT trace
    moved to y = 125 mm, and the J1 and SW1 values synced from the schematic.
    [fsk-timekeeper.kicad_pcb, fsk-timekeeper.kicad_sch]
2026-09-30 fix: interpolate held captures only between anchors that agree
    A capture held through a beacon gap was interpolated between the anchors
    around it whenever they implied a master/sensor rate between 0 and 2, so a
    wrong anchor could shift it by up to seconds while it still carried
    healthy flags. The anchors must now imply a rate within SKEW_CLAMP_PPM of 1
    (plus 1 us of capture jitter), the bound the skew check already sets on the
    normal path; otherwise the capture is a loss of unknown time.
2026-09-30 add: check PPS bridges against the neighbouring segments' frequencies
    The 200 ppm bound let a PPS phase step of k x 200 us through a bridge of
    k seconds, 1 ms across a 5 s gap. The ticks across the gap are now compared
    with k seconds at the frequencies measured on both sides: each end
    window's frequency is moved to its gap end along the trend between the two
    windows, so a crystal drifting linearly with temperature is followed, and
    the tolerance is 1 us + 1 ppm of the gap (21 us across 20 s). Without a
    measured frequency on both sides only the 200 ppm bound applies.
2026-09-30 add: stitch the GND pours with vias
    The top and bottom GND pours were joined by only nine vias and the
    through-hole pads. GND vias now run along the board edge, around the
    Ra-01SH, on a roughly 10 mm grid, and beside the ground pads of C3, R2,
    D2, U2 pin 16, U4 pin 2 and the battery negative, for 69 in total. The
    via by U3 and the one by C4 are merged into one. The +3.3V B.Cu stub past
    its via is trimmed and the zones are refilled.
    [fsk-timekeeper.kicad_pcb]
2026-09-30 fix: probe the radio with the SX126x ReadRegister frame
    RadioLib's Module keeps its default register-access framing until begin()
    switches it to the SX126x layout, so the probe sent 20 00 00... instead of
    1D 03 20 00...: the SX1262 never answered with its version string, every
    attempt failed, and no board brought its radio up. The probe now builds
    the ReadRegister frame itself (opcode, address, status byte, data) after a
    bounded BUSY wait.
    A new host test builds radio.cpp and the vendor RadioLib against a fake
    SX1262 behind a fake HAL. It checks the probe's bytes and a full
    radio_begin() down to the TCXO standby, which the MAC simulator cannot see
    because it replaces the radio API. make tes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
    [radio.cpp]
2026-09-30 fix: drop a received packet whose length reads as zero
    A failed length read gives 0, and RadioLib's readData(buf, 0) then reads
    the whole packet, up to 255 bytes, into the 96-byte receive buffer. Such a
    packet is now dropped as a receive error and reception restarts. A host
    test drives the case with the fake SX1262, next to a normal receive.
    [radio.cpp]
2026-09-30 fix: keep retrying a radio that failed to come up at boot
    A board whose radio (or HFXO) failed at boot stayed in provisioning mode
    for good: the runtime recovery never ran, so one bad start silenced a
    finish sensor for a whole event. The bring-up now retries from the main
    loop after 1 s, doubling up to 60 s, while USB provisioning keeps working,
    and each attempt counts as a radio reset. Once it succeeds the MAC starts
    as it would have at boot.
    [config.h, main.c]
2026-09-30 fix: judge a role's hole only once all its sensors have caught up
    With two sensors on one role, a final hole in one of them closed the run as
    invalid before the other sensor's reports had arrived, although those could
    still hold the crossings the result needed before the hole; the same
    evidence gave a verified run when judged a moment later, and a closed run
    never reopens. A hole now decides the run only once every sensor of its
    role is certain through it or has ended (reboot, master session end,
    capture order fault).
2026-09-30 fix: freeze a result with its own master boot's stored PPS edges
    A decided run waits up to 2 s for a qualified PPS edge before it freezes
    its calibration, and the timeline came from the live edges only while
    they belonged to the run's master boot. A master that rebooted in that
    window left the run with no edges, so it froze at the nominal 16 MHz with
    its boot's edges sitting in storage. The freeze now loads the run's own
    boot's edges from storage when the live ones belong to another boot.
2026-09-30 fix: send consecutive unknown-time losses as one range
    Every capture stamped with no usable time became its own loss record and
    took its own packet, one per beacon cycle, so a bouncing crossing of nine
    edges without sync took about nine seconds to reach the master. Contiguous
    unknown-time losses at the head of the FIFO now go as one range in one
    packet; the console already treats them as one hole.
2026-09-30 fix: count a timebase-end marker held by a full host queue once
    After a master HFXO fault the timebase-end marker was pushed again on
    every main-loop pass while the host queue was full, and every refusal
    counted as a queue overflow, so D 0's queue_overflow saturated within a
    second. The marker now waits until the queue has room.
    [main.c]
2026-09-30 fix: send the master's identity and fault report before the radio comes up
    The report of the fault that rebooted the master went out only after the
    radio bring-up, so a bring-up that hung or faulted on every boot kept its
    cause from the host. The I line and the report now go out as soon as the
    master role is known.
    [main.c]
2026-09-30 fix: find bootloader boards by serial and pass flash.bat arguments
    The Adafruit bootloader reports the same chip-id serial as the app, yet
    --serial / -Serial matched app boards only and claimed a bootloader board
    had another serial. Both scripts now match a board in the bootloader by
    its serial too, and say that an app from before chip-id serials reports
    0001, so its first update needs the port or a double-tap on RST.
    flash.bat now passes its arguments to flash.ps1.
2026-09-30 fix: drop references to the untracked plan document
    Sixteen comments and test names pointed at PLAN.md sections and work-item
    numbers (W1, W2-9, PLAN §2.4, ...), but PLAN.md is not in the repository.
    The references are gone; the text around them says what they meant.
    [main.c]
2026-09-30 fix: keep comments to three lines
    Twenty comments inside the firmware and console sources ran past the
    one-to-three-line rule; each now says the same in at most three lines.
    File header comments are unchanged.
    [board.c, config.h, gps.c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]
2026-09-30 fix: check the console's USB line fixture against the firmware formatter
    The console's firmware-lines test held hand-copied lines, so a change to the
    firmware's line format could pass both test suites. The lines now live in
    device/firmware/tests/usb_lines.txt: the host tests print every line type
    through the firmware's formatters and diff the output with the file, and the
    console test parses the same file. A fixture change also reruns the console
    workflow.
2026-09-30 fix: exclude the known ERC items so the check can pass
    The SuperMini symbol declares its GND and BAT+ pins as power outputs,
    which gives four pin_to_pin errors, and +12V is driven only by the boost
    diode, a passive pin. The project now excludes those five markers, so ERC
    reports nothing and a new violation stands out. The exclusion keys hold
    marker positions: moving U1 or #PWR015 brings the items back.
2026-09-30 fix: remove the track pieces that lie inside pads
    Drop 39 short segments that sit entirely inside pads, including the two
    stubs on the unconnected U1 pads 17 and 19. Vias and footprints are
    unchanged and the zones are refilled.
    [fsk-timekeeper.kicad_pcb]
2026-09-30 fix: keep hand-soldered parts out of the JLCPCB BOM and CPL
    BT1, J1, L1, SW1, U2 and U4 have no LCSC number but still went into the
    BOM and CPL, and U1 into the CPL, so JLCPCB would list them as unmatched
    lines. Their symbols and footprints are now excluded from the BOM and
    position files, and the assembly plugin's project.db follows.
    [fsk-timekeeper.kicad_pcb, fsk-timekeeper.kicad_sch]
2026-09-30 add: JLCPCB fabrication files from the assembly plugin
    Gerbers, drill files, BOM and CPL written by kicad-jlcpcb-tools from the
    current board: 11 BOM lines, all with LCSC numbers, and 15 placements.
    D2 and U3 carry the plugin's -90 degree SOT-23 rotation correction.
    [BOM-fsk-timekeeper.csv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]
